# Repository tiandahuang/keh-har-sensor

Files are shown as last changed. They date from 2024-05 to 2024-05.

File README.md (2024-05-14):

# A Kinetic Energy Harvesting (KEH) sensor for Human Activity Recognition (HAR)
 
Design files for my thesis titled "Design of a Batteryless Sensor for Human Activity Recognition", submitted May 2024 towards an MS in Electrical and Computer Engineering at the University of Texas Austin and advised by Dr. Radu Marculescu.

## Abstract

Recent advancements in sensing technology coupled with the proliferation of
cheap, low power computing have enabled the growing popularity of wearable sensors
in everyday activities. Inertial sensing, particularly for human activity recognition
(HAR), has emerged as a ubiquitous tool across fitness, healthcare, and entertainment
applications. However, conventional wearable sensors rely on batteries, introducing
limitations in cost, environmental impact, and user burden.

This thesis explores a solution to the limitations of battery-powered operation
with the design and implementation of a wearable, kinetic energy harvesting (KEH)
powered wireless inertial sensor for batteryless HAR. The KEH-powered sensor is
energy optimized to require only 140µJ per set of accelerometer samples, translating
to an average power draw of 90µJ during continuous operation. The idle power
consumption is only 9.2µW while connected over Bluetooth. Energy harvesting is
achieved by a rotational unbalanced mass electromagnetic harvester with a peak
power output of 1.3mW.

## Device Summary

#### The full device assembly: The device is designed and assembled entirely from scratch. 

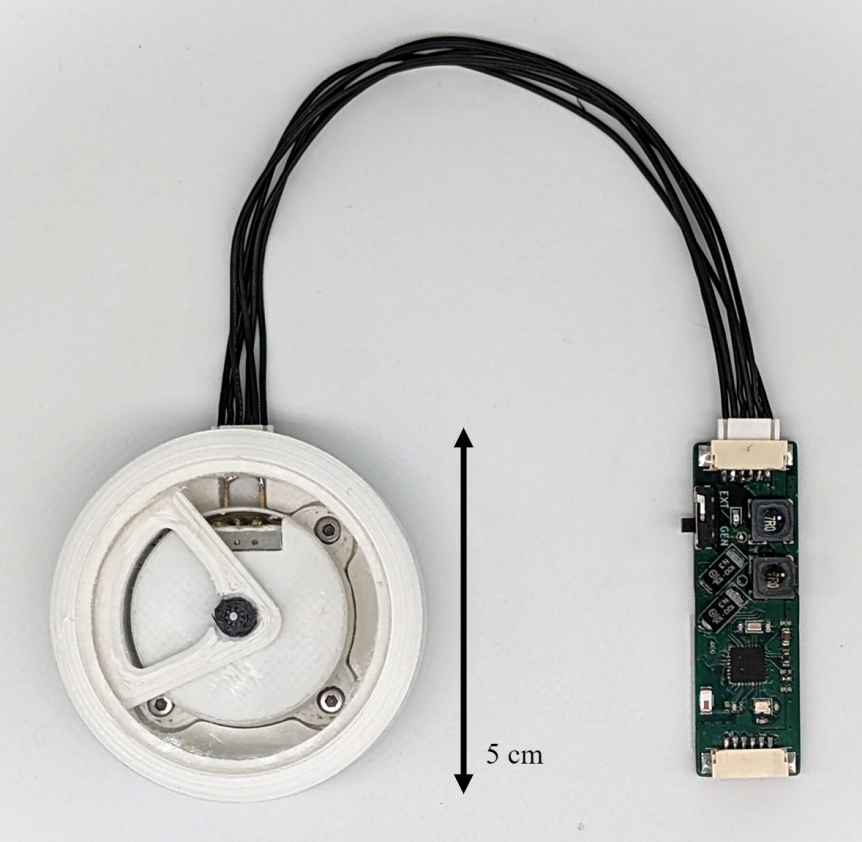
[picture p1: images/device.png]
full device


#### Component view of the entire device. Enclosures are located on the top row. There are four functional components, split between the Kinetic Energy Harvesting (KEH) Module (offset mass, rotor, stator), and the Power Conversion and Sensing/Communication Modules (PCB).

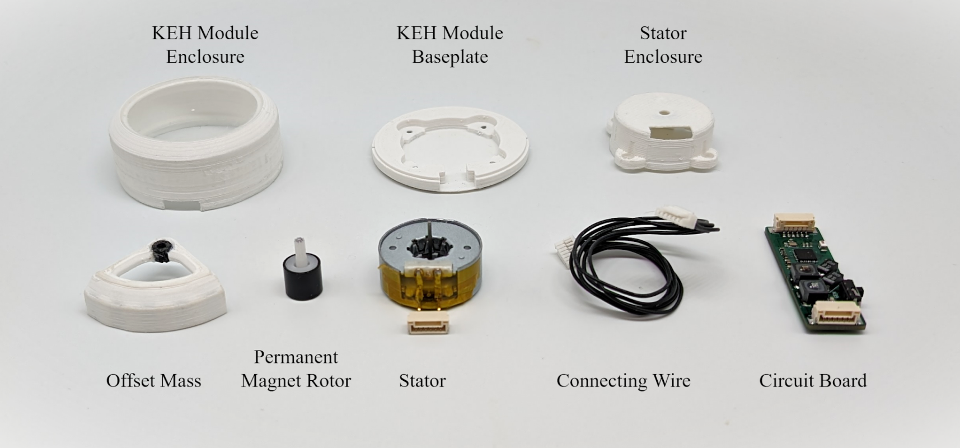
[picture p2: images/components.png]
device components


#### Full device block diagram. Energy harvested by the KEH Module (left) is converted to usable power by the Power Module (middle), which is used to sample an accelerometer and to transmit data by the Sensing Module (right). Energy storage capacitors buffer the usable power.

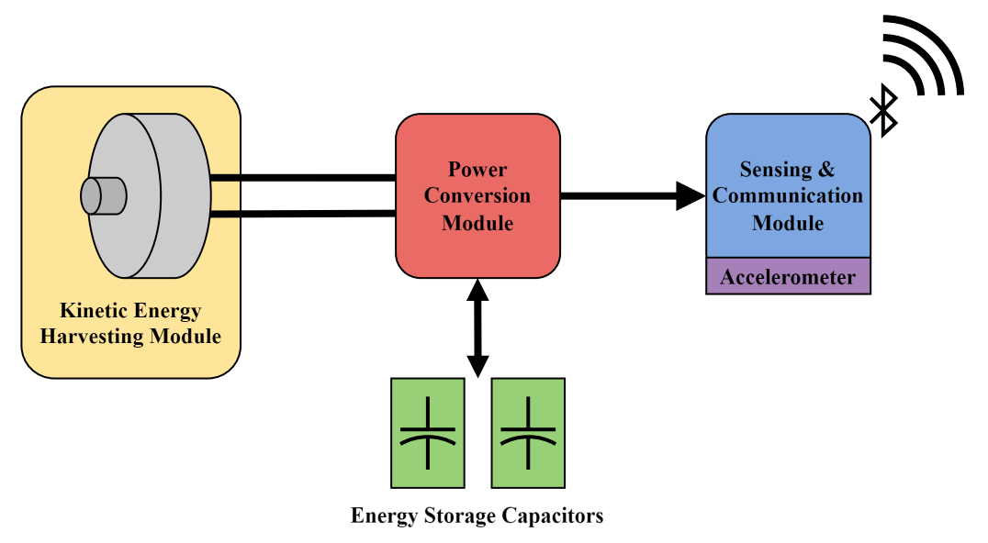
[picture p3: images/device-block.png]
device block diagram


## Physical Design

*Files are located in `./3d/*`*

The physical operation the device centers around the KEH Module, custom-designed to address the relatively high power requirements and tight space constraints of the wearable KEH sensor. The KEH Module is a rotational unbalanced mass EM harvester; this type of harvester is implemented using a statically-mounted stator and a rotor containing a permanent magnet and an attached offset mass. 

The KEH Module and its enclosure are primarily comprised of 3D-printed polylactic acid (PLA) thermoplastic. The top of the KEH Module is a 3mm acrylic panel, stiffening the assembly and providing stability to the top of the rotor. The stator and rotor are retrieved from a 28BYJ-48 geared unipolar stepper motor. For this application, the gears are removed and the stator is modified to be bipolar. The offset mass is also constructed from PLA, with steel M3 screws and fasteners for added weight. The mass totals 8.7g with a radius of 20mm.

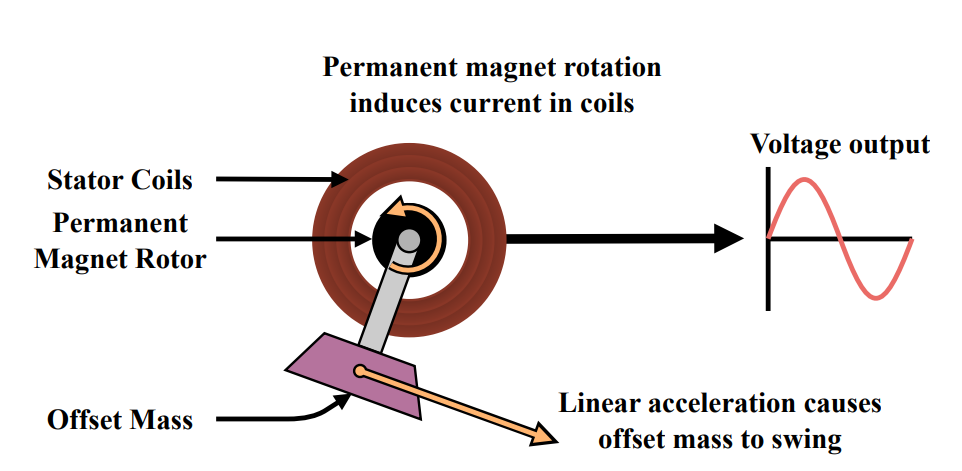
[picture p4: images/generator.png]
physical operation


## Firmware Design

*Files are located in `./firmware/*`*

The firmware architecture of device adheres to an event-driven paradigm, with a target of minimizing processor occupancy. By transferring execution context between various hardware-driven interrupt handlers, the total amount of processing time can be reduced. 

Initialization must be separated into a low-level initialization and BLE initialization
due to the significant power requirements of BLE: BLE initialization includes connecting to a listening device, which has an energy budget orders of magnitude higher than low-level initialization. 

After initialization is completed (including completing a BLE connection),
context is fully transferred to a series of hardware-driven interrupts. In steady-state
operation, all system execution is triggered by a periodic timer interrupt running every
100ms. The interrupt handler initiates ADC sampling; upon completion of the ADC
sample a subsequent hardware interrupt is triggered, executing energy-monitoring
logic. If energy is sufficient for the accelerometer to sample a set of data and for a
BLE packet to be sent, the accelerometer is woken up. Running independently of the
MCU, the accelerometer stores 16 samples of data within an internal first-in-first-out
buffer (FIFO). The filling of this FIFO then triggers a hardware interrupt in the
MCU, signaling the MCU to retrieve the FIFO data and to transmit the data over
BLE.

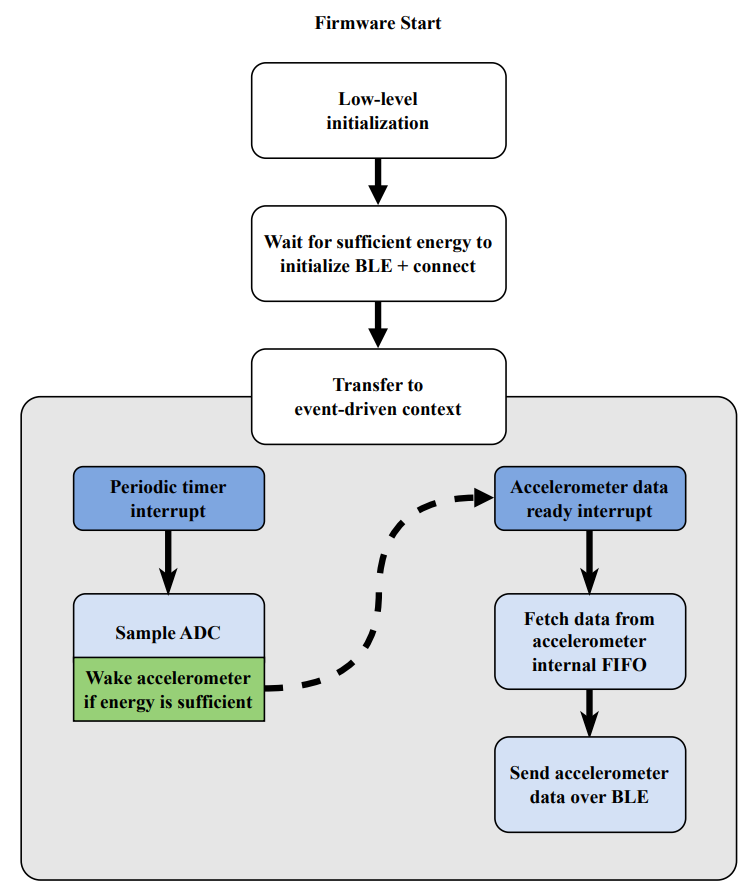
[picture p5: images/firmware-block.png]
firmware block diagram


## Electrical Design

*Files are located in `./pcb/*`*

A single PCB contains all electrical circuitry required for operation. This can be segmented into two modules, the Power Conversion Module and the Sensing/Communication Module. The Power Module contains the PMIC and energy storage; the Sensing Module contains the MCU and the accelerometer. 

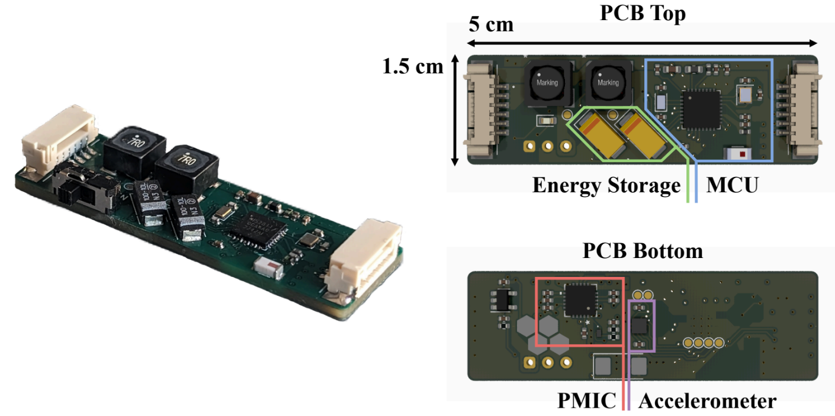
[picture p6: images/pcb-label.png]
pcb with labels


### Power Conversion Module

The Power Module performs a wide array of power regulation-related functions, needed to convert the KEH generator's low and variable peak-to-peak output voltage into a stable, usable VDD for the Sensing Module. The following functions are included:

1. **Amplification**: Coupled inductors and a transformer driver (similar in topology to an isolated synchronous boost converter) amplify the weak voltage output from the generator into a high peak-to-peak AC signal; this reduces diode voltage losses from rectification.
2. **Rectification**: A full-wave rectifier converts the input AC voltage into DC. This DC voltage must be high enough to step down to the final VDD.
3. **Step-Down Conversion & Regulation**: A switching regulator steps down the unstable DC output from the rectifier to the final VDD.
4. **Charge Management**: A bidirectional gate switches between charging storage capacitors (with excess energy) and discharging storage capacitors.

### Sensing/Communication Module

The Sensing Module contains an SPI-enabled triaxial accelerometer and a BLE MCU. Electrically, the implementation follows their respective datasheets.

### Major Components

| **Component** | **Part Number** | **Purpose** |
|:---:|:---:|:---:|
| PMIC | LTC3109 | Power rectification and management |
| BLE/MCU | nRF52811 | System control, data transmission |
| Accelerometer | BMA400 | Triaxial acceleration sampling, data buffering |

## Power Performance

### Power Generation

| **Measurement** | **Value** |
|:---:|:---:|
| Peak Voltage  | 350 mV  |
| Peak Current  | 4 mA |
| Peak Power | 1.3 mW  |

### Power Consumption

| **Event** | **Value** |
|:---:|:---:|
| Inrush | 23 µJ |
|  Hardware Initialization | 48 µJ |
| BLE Initialization | 620 µJ  |
| ADC Sample |  0.88 µJ  |
| Accelerometer & BLE Send | 102 µJ  |
| Leakage (Device Idle)  | 9.2 µW  |
|  Leakage (Open Circuit)  | 6 µW |

## File Structure

| **Folder** | **Description** | **Tool/Toolchain** |
|---|---|---|
| ./firmware | Device firmware and project files | SEGGER 5.42a |
| ./pcb | PCB schematic, layout, and project files | KiCAD 7.0 |
| ./3d | CAD files for generator and enclosures | SOLIDWORKS 2022 |

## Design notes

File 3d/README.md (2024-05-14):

*Please excuse the horrid naming.*

All parts are 3D printed using PLA, with the exception of `glass.SLDPRT`, which is laser-cut 1/8" acrylic. Mass is added to the PLA arm using embedded M3 bolts/nuts (total mass = 8.7g).

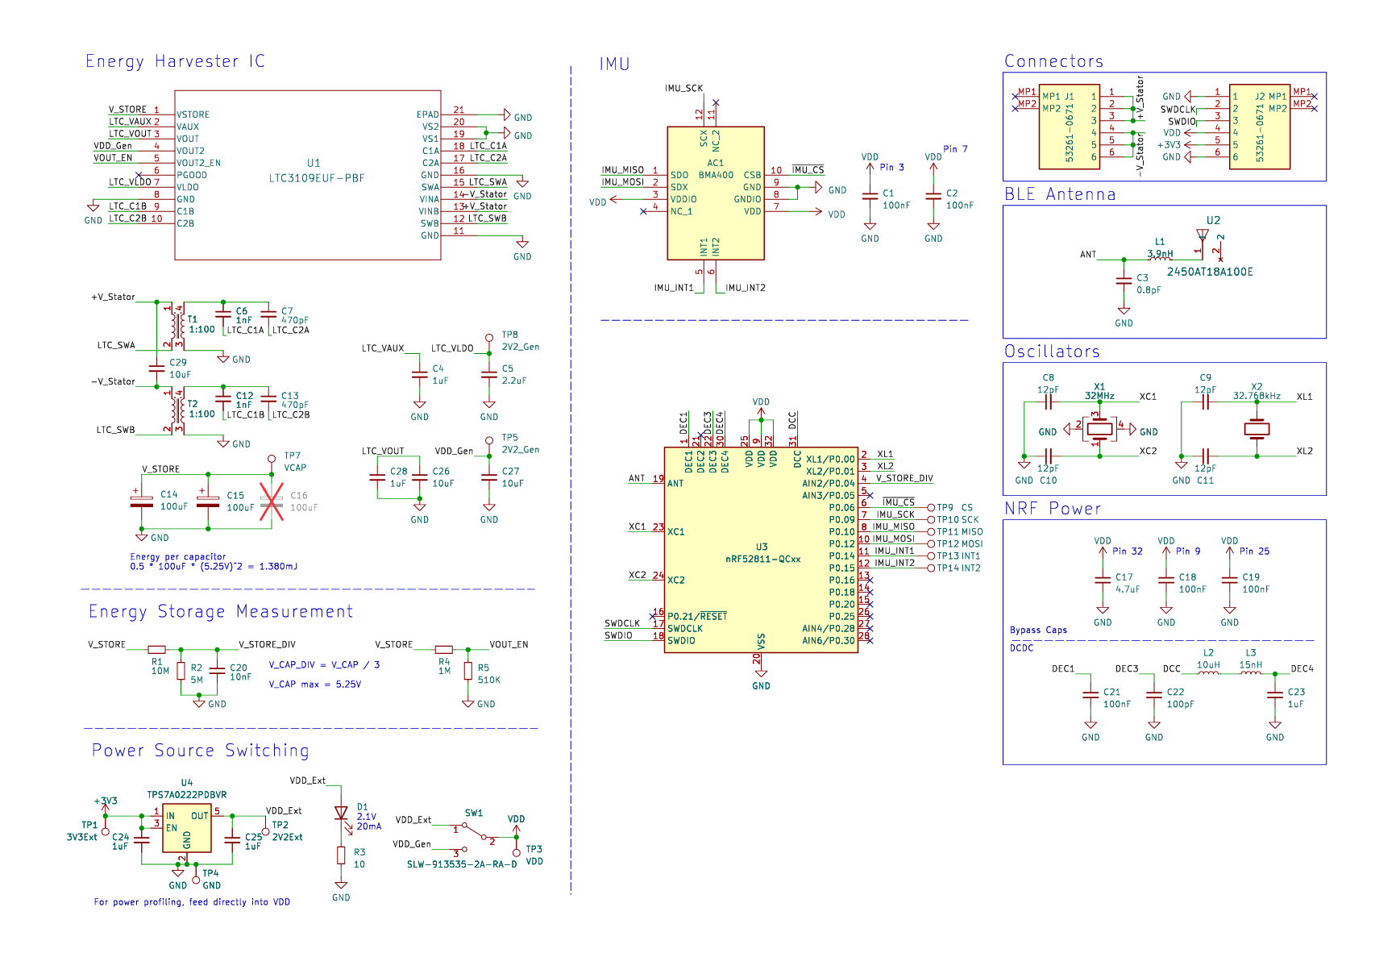
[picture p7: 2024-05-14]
pcb/images/schematic.png

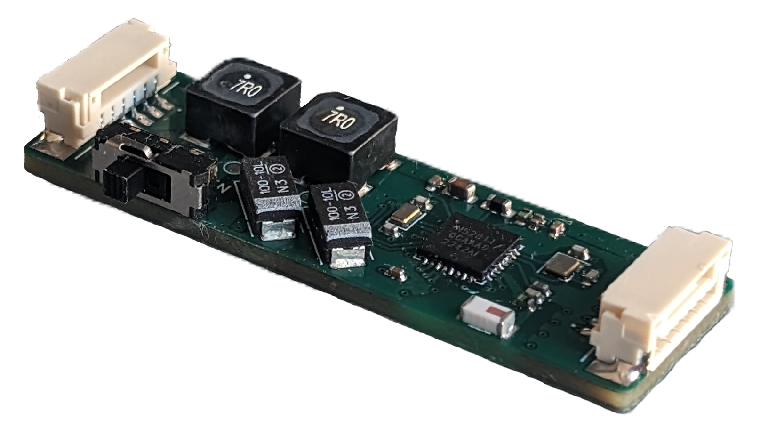
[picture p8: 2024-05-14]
pcb/images/pcb-actual.png

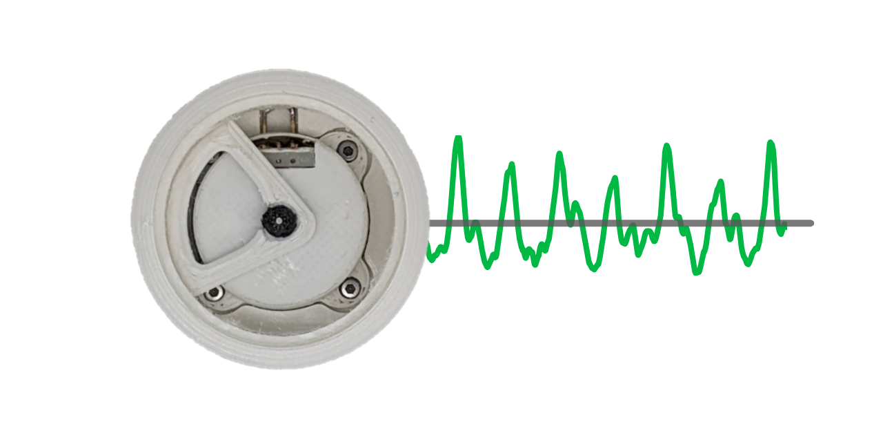
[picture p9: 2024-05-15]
images/preview.png

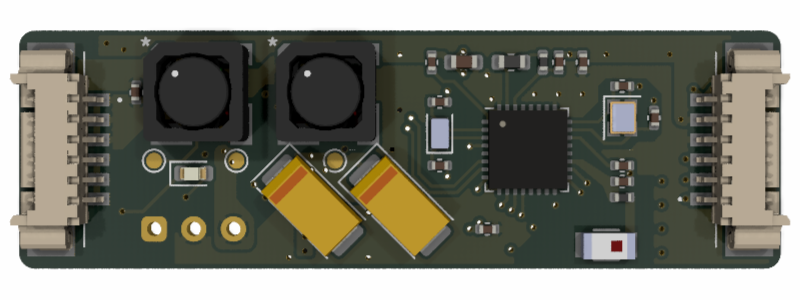
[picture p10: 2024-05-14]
pcb/images/imu-harvester-front.png

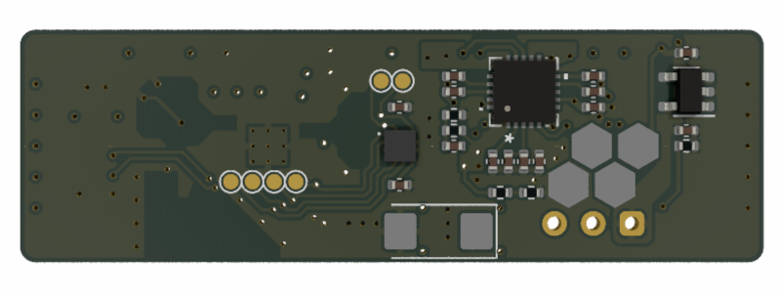
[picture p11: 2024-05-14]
pcb/images/imu-harvester-back.png

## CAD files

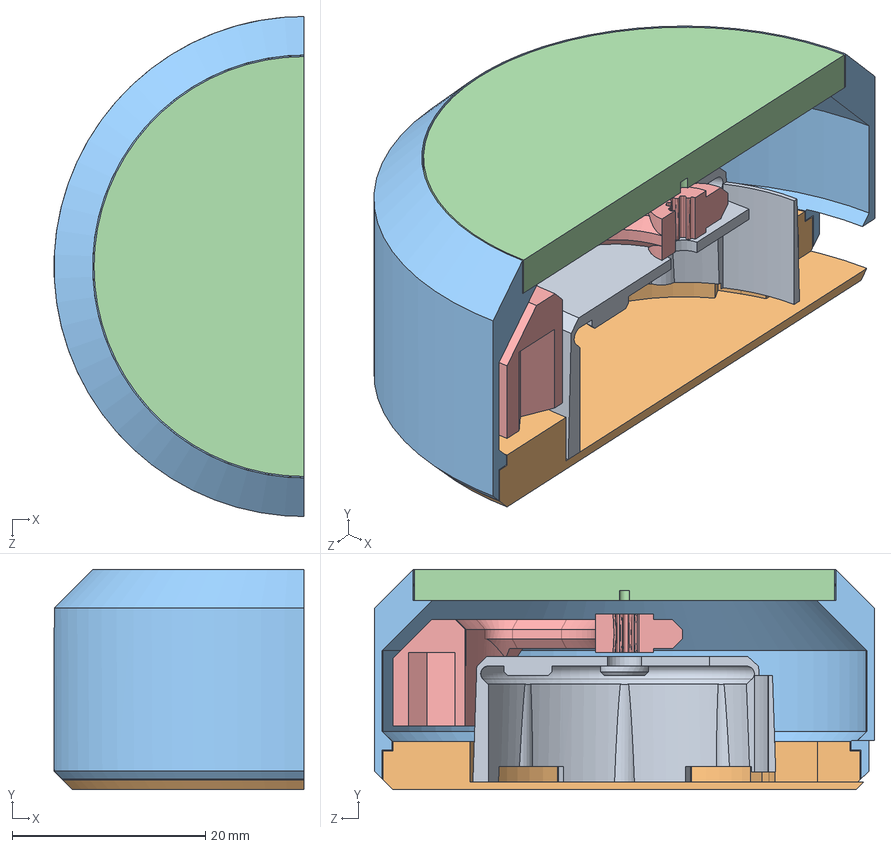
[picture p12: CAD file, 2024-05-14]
3d/0.SLDASM
25.9 x 22.8 x 51.8 mm
base
base2
base3
glass
arm

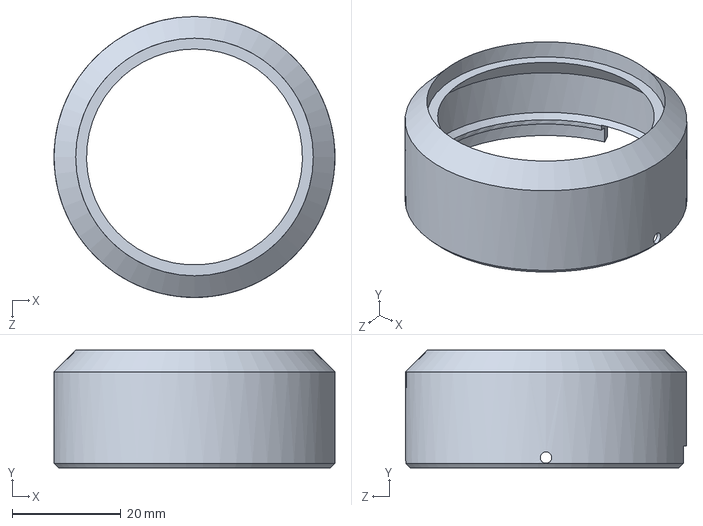
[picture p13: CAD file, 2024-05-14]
3d/base3.SLDPRT
51.8 x 21.7 x 51.8 mm

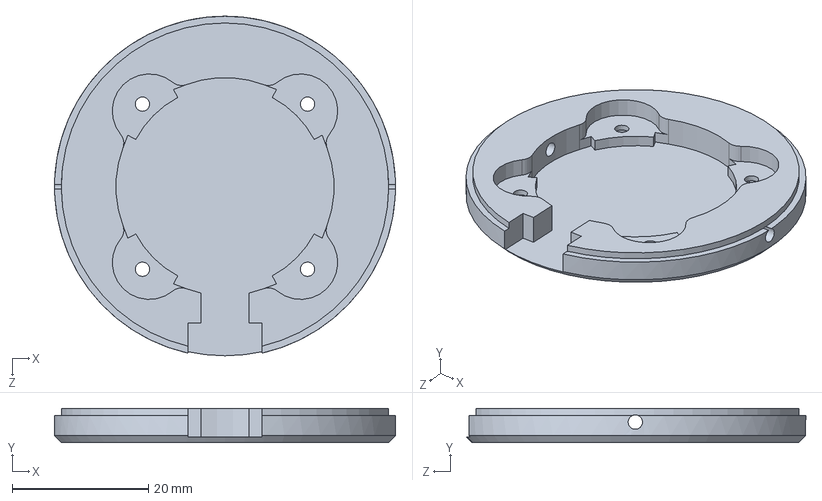
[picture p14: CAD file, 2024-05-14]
3d/base2.SLDPRT
50.0 x 5.00 x 49.8 mm

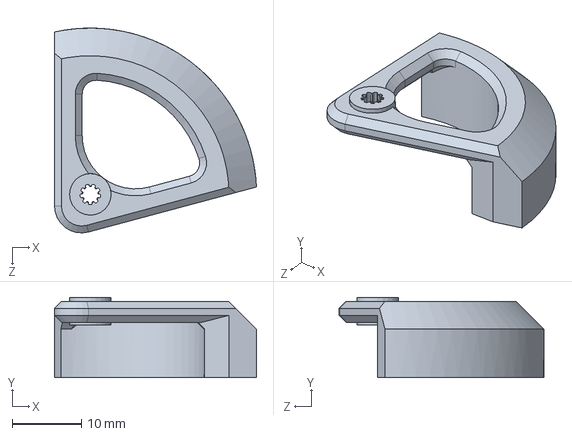
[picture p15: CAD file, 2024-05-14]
3d/arm.SLDPRT
29.2 x 11.6 x 29.6 mm

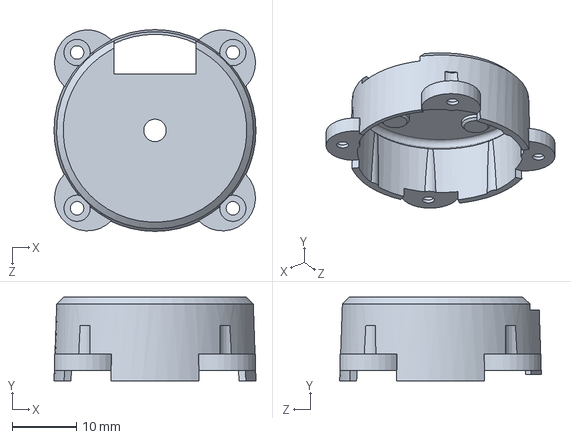
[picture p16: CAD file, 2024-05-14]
3d/base.SLDPRT
31.4 x 13.0 x 31.4 mm

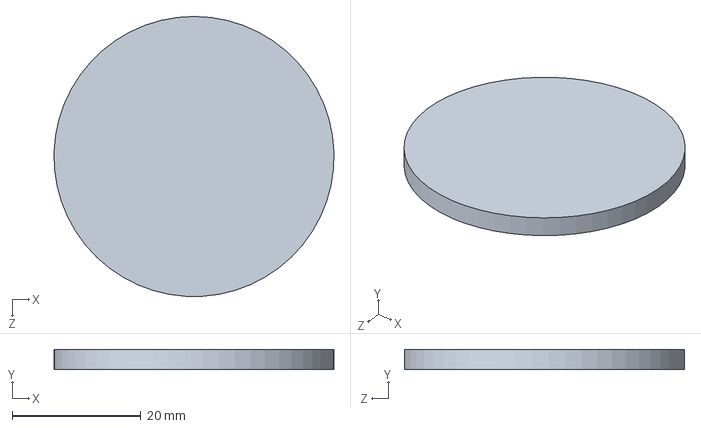
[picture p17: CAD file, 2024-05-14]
3d/glass.SLDPRT
43.5 x 3.17 x 43.5 mm

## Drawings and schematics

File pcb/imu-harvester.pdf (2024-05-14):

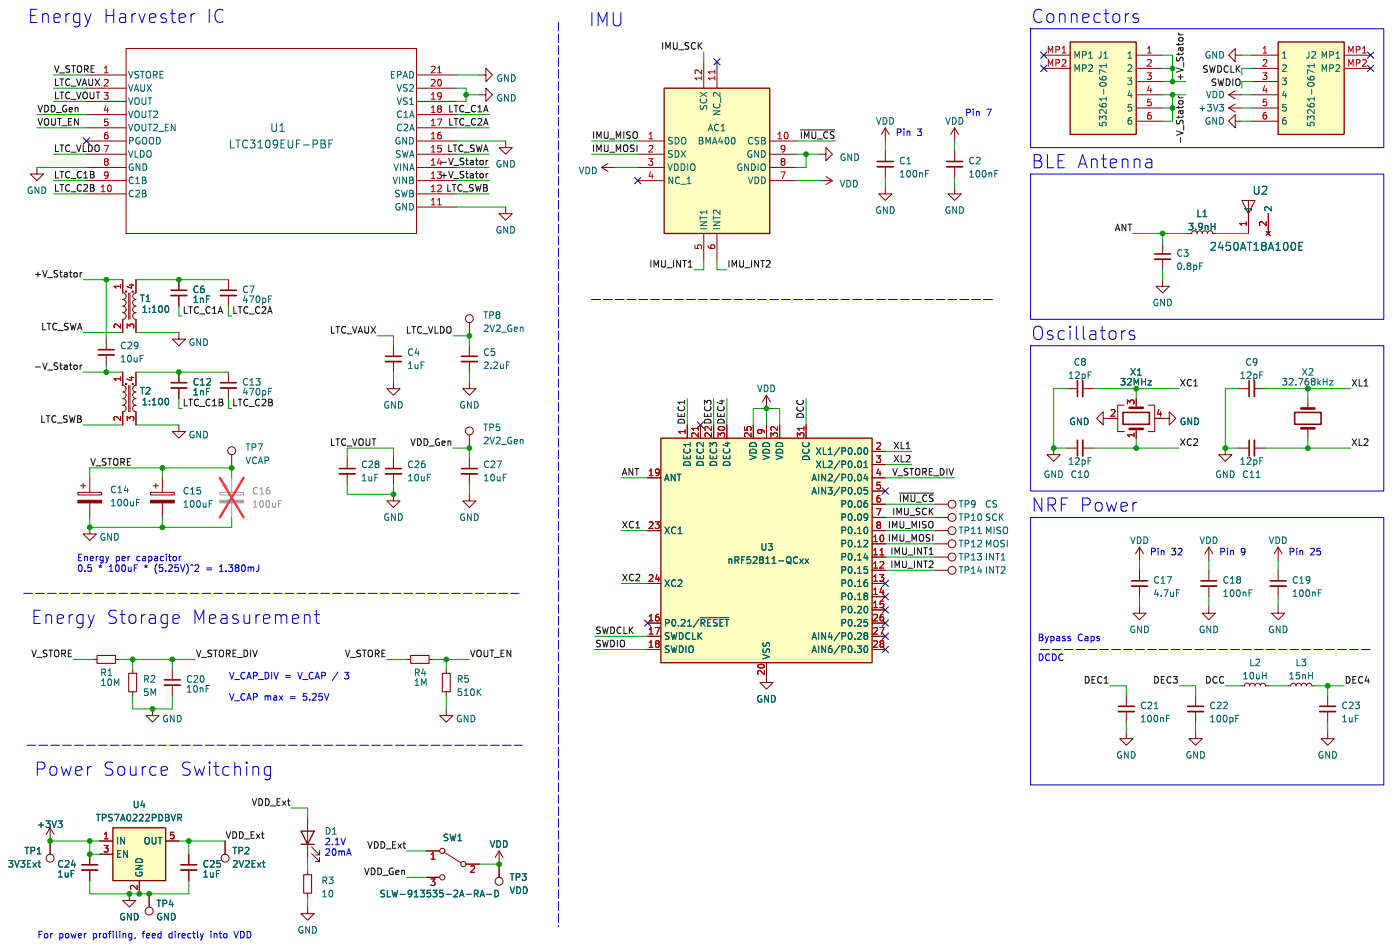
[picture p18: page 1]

1 P0.12 10 P0.14 11 P0.15 12 P0.16 13 P0.18 14 P0.20 15 P0.21/~{RESET} 16 SWDCLK 17 SWDIO 18 ANT 19 XL1/P0.00 2 VSS 20 DEC2 21 DEC3 22 XC1 23 XC2 24 VDD 25 P0.25 26 AIN4/P0.28 27 AIN6/P0.30 28 XL2/P0.01 3 DEC4 30 DCC 31 VDD 32 AIN2/P0.04 4 AIN3/P0.05 5 P0.06 6 P0.09 7 P0.10 8 VDD
nRF52811-QCxx GND

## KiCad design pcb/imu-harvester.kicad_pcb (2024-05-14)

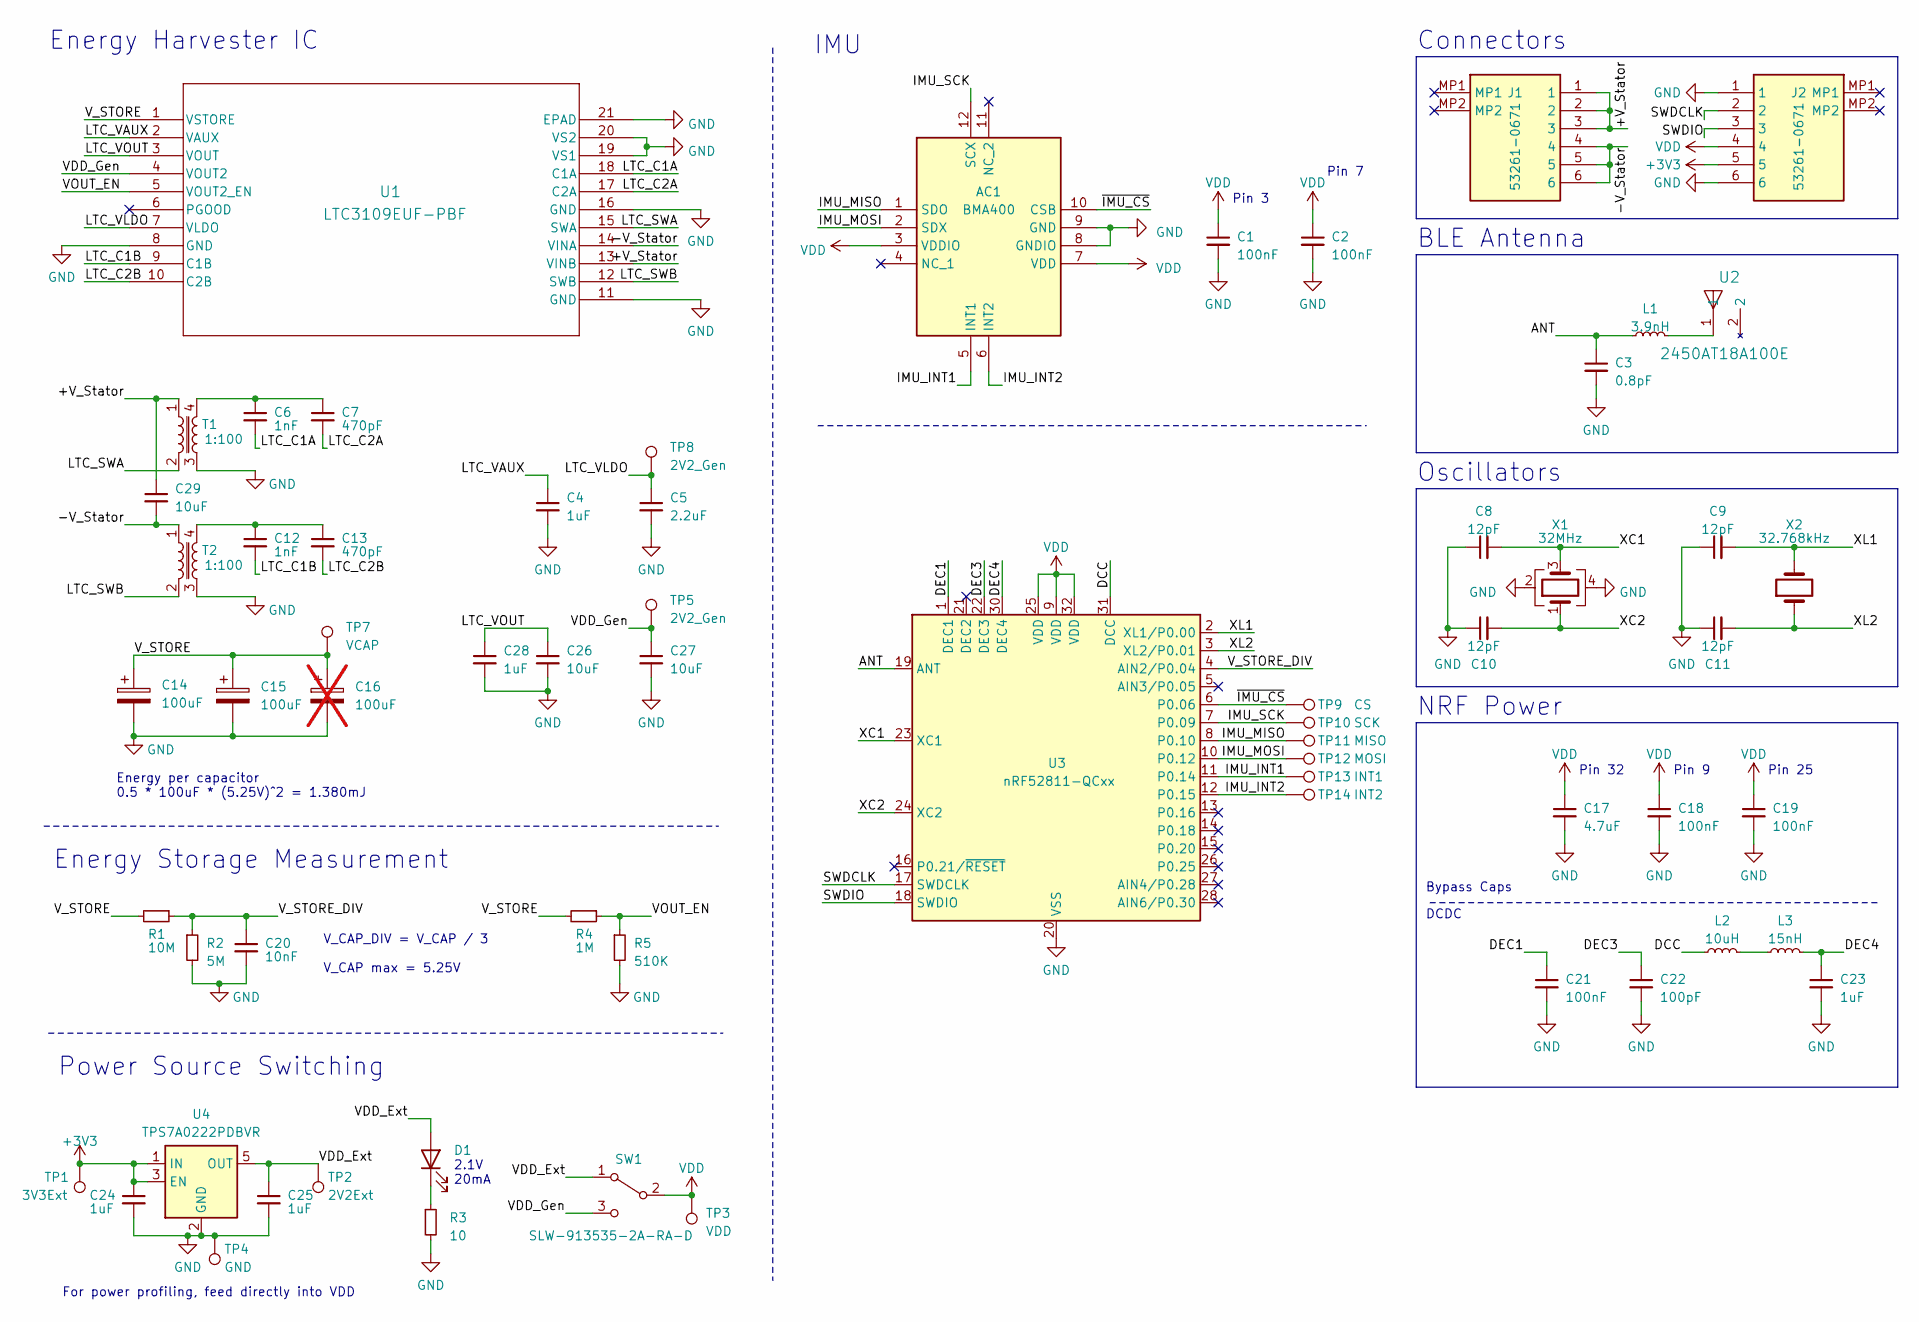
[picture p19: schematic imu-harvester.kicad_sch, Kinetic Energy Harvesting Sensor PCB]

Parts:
AC1: BMA400; BOSCH_LGA-12; Mouser Part Number 262-BMA400
C1, C2, C18, C19, C21: 100nF; C_0402_1005Metric; Manufacturer_Part_Number KGM05AR71C104KN
C3: 0.8pF; C_0402_1005Metric; Manufacturer_Part_Number GRM1555C1ER80BA01D
C4, C23, C24, C25, C28: 1uF; C_0402_1005Metric; Manufacturer_Part_Number CM05X7R105K06AH-HE
C5: 2.2uF; C_0402_1005Metric; Manufacturer_Part_Number GRM155Z71A225KE01D
C6, C12: 1nF; C_0402_1005Metric; Manufacturer_Part_Number C0402C102KCRACAUTO
C7, C13: 470pF; C_0402_1005Metric; Manufacturer_Part_Number KGM05ACG1H471JH
C8, C9, C10, C11: 12pF; C_0402_1005Metric; Manufacturer_Part_Number KGM05ACG1H120JN
C14: 100uF; CP_EIA-6032-28_Kemet-C; Manufacturer_Part_Number TL3C107K010C0200
C15: 100uF; CP_EIA-6032-28_Kemet-C
C16: 100uF; CP_EIA-6032-28_Kemet-C; not fitted
C17: 4.7uF; C_0603_1608Metric; Manufacturer_Part_Number GRM188Z71C475KE21D
C20: 10nF; C_0402_1005Metric; Manufacturer_Part_Number C0402C103K1RACAUTO
C22: 100pF; C_0402_1005Metric; Manufacturer_Part_Number KGM05ACG1H101JN
C26, C29: 10uF; C_0402_1005Metric; Manufacturer_Part_Number CM05X7R105K06AH-HE
C27: 10uF; C_0402_1005Metric; Manufacturer_Part_Number GRM155Z71A225KE01D
D1: LO Q976.01-P2R2-25-1; LED_0603_1608Metric; Manufacturer_Part_Number LO Q976.01-P2R2-25-1
J1, J2: 53261-0671; 532610671; Mouser Part Number 538-53261-0671
L1: 3.9nH; L_0402_1005Metric; Manufacturer_Part_Number LQG15WZ3N9B02D
L2: 10uH; L_0603_1608Metric; Manufacturer_Part_Number KLZ1608MHR100WTD25
L3: 15nH; L_0402_1005Metric; Manufacturer_Part_Number LQG15WZ15NG02D
R1: 10M; R_0402_1005Metric; Manufacturer_Part_Number RCC040210M0FKED
R2: 5M; R_0402_1005Metric; Manufacturer_Part_Number CRCW04024M99FKED
R3: 10; R_0402_1005Metric; Manufacturer_Part_Number RCC040210R0FKED
R4: 1M; R_0402_1005Metric; Manufacturer_Part_Number RCC040210M0FKED
R5: 510K; R_0402_1005Metric; Manufacturer_Part_Number CRCW04024M99FKED
SW1: SLW-913535-2A-RA-D; Manufacturer_Part_Number SLW-913535-2A-RA-D
T1, T2: 1:100; 74488540070; Manufacturer_Part_Number 74488540070
TP1: 3V3Ext; Testpoint_Hex_D3.0
TP2: 2V2Ext; Testpoint_Hex_D3.0
TP3: VDD; Testpoint_Hex_D3.0
TP4: GND; Testpoint_Hex_D3.0
TP5, TP8: 2V2_Gen; TestPoint_Pad_D1.0mm
TP7: VCAP; TestPoint_Pad_D1.0mm
TP9: CS; TestPoint_Pad_D1.0mm
TP10: SCK; TestPoint_Pad_D1.0mm
TP11: MISO; TestPoint_Pad_D1.0mm
TP12: MOSI; TestPoint_Pad_D1.0mm
TP13: INT1; TestPoint_Pad_D1.0mm
TP14: INT2; TestPoint_Pad_D1.0mm
U1: LTC3109EUF-PBF; QFN-20_UF_LIT; Manufacturer_Part_Number LTC3109EUF#PBF
U2: 2450AT18A100E; 2450AT18A100E_JOT; Manufacturer_Part_Number 2450AT18A100E
U3: nRF52811-QCxx; QFN-32-1EP_5x5mm_P0.5mm_EP3.6x3.6mm_ThermalVias; Manufacturer_Part_Number nRF52811-QCAA-R
U4: TPS7A0222PDBVR; SOT-23-5; Manufacturer_Part_Number TPS7A0222PDBVR
X1: 32MHz; Crystal_SMD_2016-4Pin_2.0x1.6mm; Manufacturer_Part_Number ECS-320-8-37B2-JTY-TR
X2: 32.768kHz; Crystal_SMD_2012-2Pin_2.0x1.2mm; Manufacturer_Part_Number ECS-.327-9-12R-TR

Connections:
+3V3: C24.1, J2.5, TP1.1, U4.1 (IN), U4.3 (EN)
/+V_Stator: C29.1, J1.1, J1.2, J1.3, T1.1, U1.13 (VINB)
/-V_Stator: C29.2, J1.4, J1.5, J1.6, T2.1, U1.14 (VINA)
/ANT: C3.1, L1.1, U3.19 (ANT)
/DCC: L2.1, U3.31 (DCC)
/DEC1: C21.1, U3.1 (DEC1)
/DEC3: C22.1, U3.22 (DEC3)
/DEC4: C23.1, L3.2, U3.30 (DEC4)
/IMU_INT1: AC1.5 (INT1), TP13.1, U3.11 (P0.14)
/IMU_INT2: AC1.6 (INT2), TP14.1, U3.12 (P0.15)
/IMU_MISO: AC1.1 (SDO), TP11.1, U3.8 (P0.10)
/IMU_MOSI: AC1.2 (SDX), TP12.1, U3.10 (P0.12)
/IMU_SCK: AC1.12 (SCX), TP10.1, U3.7 (P0.09)
/LTC_C1A: C6.2, U1.18 (C1A)
/LTC_C1B: C12.2, U1.9 (C1B)
/LTC_C2A: C7.2, U1.17 (C2A)
/LTC_C2B: C13.2, U1.10 (C2B)
/LTC_SWA: T1.2, U1.15 (SWA)
/LTC_SWB: T2.2, U1.12 (SWB)
/LTC_VAUX: C4.1, U1.2 (VAUX)
/LTC_VLDO: C5.1, TP8.1, U1.7 (VLDO)
/LTC_VOUT: C26.1, C28.1, U1.3 (VOUT)
/SWDCLK: J2.2, U3.17 (SWDCLK)
/SWDIO: J2.3, U3.18 (SWDIO)
/VDD_Ext: C25.1, D1.2 (A), SW1.1 (A), TP2.1, U4.5 (OUT)
/VDD_Gen: C27.1, SW1.3 (C), TP5.1, U1.4 (VOUT2)
/VOUT_EN: R4.1, R5.1, U1.5 (VOUT2_EN)
/V_STORE: C14.1, C15.1, C16.1, R1.2, R4.2, TP7.1, U1.1 (VSTORE)
/V_STORE_DIV: C20.1, R1.1, R2.1, U3.4 (AIN2/P0.04)
/XC1: C8.2, U3.23 (XC1), X1.3
/XC2: C10.2, U3.24 (XC2), X1.1
/XL1: C9.2, U3.2 (XL1/P0.00), X2.2
/XL2: C11.2, U3.3 (XL2/P0.01), X2.1
/~IMU_CS: AC1.10 (CSB), TP9.1, U3.6 (P0.06)
GND: AC1.8 (GNDIO), AC1.9 (GND), C1.2, C2.2, C3.2, C4.2, C5.2, C8.1, C9.1, C10.1, C11.1, C14.2, C15.2, C16.2, C17.2, C18.2, C19.2, C20.2, C21.2, C22.2, C23.2, C24.2, C25.2, C26.2, C27.2, C28.2, J2.1, J2.6, R2.2, R3.2, R5.2, T1.3, T2.3, TP4.1, U1.8 (GND), U1.11 (GND), U1.16 (GND), U1.19 (VS1), U1.20 (VS2), U1.21 (EPAD), U3.20 (VSS), U3.29 (VSS), U3.33 (VSS), U4.2 (GND), X1.2, X1.4
unnamed: C6.1, C7.1, T1.4
unnamed: C12.1, C13.1, T2.4
unnamed: D1.1 (K), R3.1
unnamed: L1.2, U2.1
unnamed: L2.2, L3.1
VDD: AC1.3 (VDDIO), AC1.7 (VDD), C1.1, C2.1, C17.1, C18.1, C19.1, J2.4, SW1.2 (B), TP3.1, U3.9 (VDD), U3.25 (VDD), U3.32 (VDD)

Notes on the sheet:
V_CAP_DIV = V_CAP / 3 V_CAP max = 5.25V
Energy Storage Measurement
Pin 3
Power Source Switching
Pin 9
NRF Power
Connectors
DCDC
IMU
2.1V 20mA
Bypass Caps
BLE Antenna
Oscillators
Energy per capacitor 0.5 * 100uF * (5.25V)^2 = 1.380mJ
Pin 32
For power profiling, feed directly into VDD
Pin 25
Energy Harvester IC
Pin 7

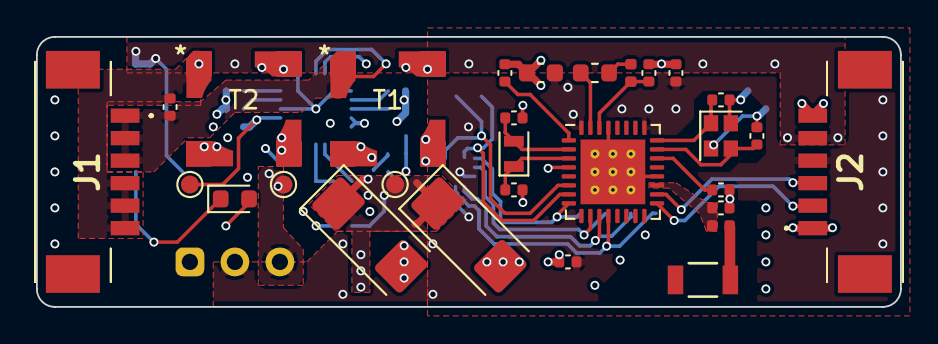
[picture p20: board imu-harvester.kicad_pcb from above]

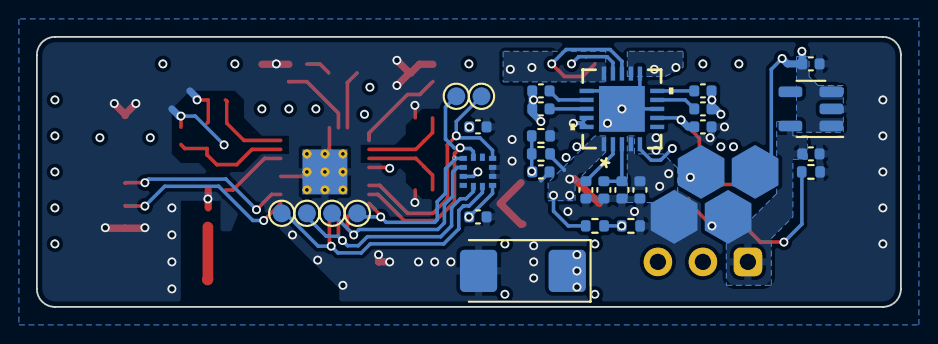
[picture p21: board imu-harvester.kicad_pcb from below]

Board: 4 copper layers, 48.0 x 15.0 mm, 63 parts (33 on the bottom side), 41 nets.

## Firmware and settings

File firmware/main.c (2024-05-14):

/**
 * Copyright (c) 2014 - 2021, Nordic Semiconductor ASA
 *
 * All rights reserved.
 *
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
 * 3. Neither the name of Nordic Semiconductor ASA nor the names of its
 *    contributors may be used to endorse or promote products derived from this
 *    software without specific prior written permission.
 *
 * 4. This software, with or without modification, must only be used with a
 *    Nordic Semiconductor ASA integrated circuit.
 *
 * 5. Any software provided in binary form under this license must not be reverse
 *    engineered, decompiled, modified and/or disassembled.
 *
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
 */

#include "app_common.h"
#include "app_debug.h"
#include "nrf.h"
#include "nrf_pwr_mgmt.h"
#include "nrfx_gpiote.h"
#include "nrfx_clock.h"
#include "nrf_sdh.h"

#include "app_timer.h"
#include "app_scheduler.h"

#include "app_ble_nus.h"
#include "app_accelerometer.h"
#include "app_voltage.h"

#define APP_SCHED_EVENT_SIZE    APP_TIMER_SCHED_EVENT_DATA_SIZE
#define APP_SCHED_QUEUE_SIZE    10

/**@brief Function for assert macro callback.
 *
 * @details This function will be called in case of an assert in the SoftDevice.
 *
 * @warning This handler is an example only and does not fit a final product. You need to analyse
 *          how your product is supposed to react in case of Assert.
 * @warning On assert from the SoftDevice, the system can only recover on reset.
 *
 * @param[in] line_num    Line number of the failing ASSERT call.
 * @param[in] p_file_name File name of the failing ASSERT call.
 */
void assert_nrf_callback(uint16_t line_num, const uint8_t *p_file_name) {
    app_error_handler(42, line_num, p_file_name);
}

/**@brief Function for handling the idle state (main loop).
 *
 * @details If there is no pending log operation, then sleep until next the next event occurs.
 */
static void idle_state_handle(void) {
    if (debug_process() == false) {
        nrf_pwr_mgmt_run();
    }
}

#if POWER_PROFILING_ENABLED
static void start_sampling_accel(void *p_event_data, uint16_t event_size) {
    debug_log("(debug timer) v store %d", voltage_read_v_store());
    debug_log("(debug timer) accelerometer set to wake");
    accelerometer_wake(true, true);
}

APP_TIMER_DEF(accel_sample_timer_id);
void accel_sample_handler(void *p_context) {
    app_sched_event_put(NULL, 0, start_sampling_accel);
}

void power_profiling_init(void) {
    debug_log("power profiling enabled. starting timer with period "STRINGIFY(POWER_PROFILING_PERIOD_MS)" ms");
    
    ret_code_t err_code;
    err_code = app_timer_create(&accel_sample_timer_id,
                                APP_TIMER_MODE_REPEATED,
                                accel_sample_handler);
    err_code = app_timer_start(accel_sample_timer_id,
                               APP_TIMER_TICKS(POWER_PROFILING_PERIOD_MS),
                               NULL);
}
#endif

/**@brief Application main function.
 */
int main(void) {

    // Initialize.
    nrf_pwr_mgmt_init();
    debug_init();
    nrfx_gpiote_init();
    APP_SCHED_INIT(APP_SCHED_EVENT_SIZE, APP_SCHED_QUEUE_SIZE);
    nrf_sdh_enable_request();

    app_timer_init();
    accelerometer_init();
    voltage_init();

    #if POWER_PROFILING_ENABLED

    power_profiling_init();

    #else 

    debug_log("finished HW init. waiting for enough energy to init BLE."); debug_force_flush();
    voltage_wait_for_v_store_thresh(V_STORE_LVL_BLE_INIT);

    #endif
    
    debug_log("initializing BLE");

    // Start BLE
    ble_all_services_init();
    advertising_start(false);

    app_timer_init();
    voltage_init();

    // Start execution.
    debug_log("initialization finished");

    // Enter main loop.
    while (true) {
        app_sched_execute();
        idle_state_handle();
    }
}

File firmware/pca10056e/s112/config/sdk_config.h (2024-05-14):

/**
 * Copyright (c) 2017 - 2021, Nordic Semiconductor ASA
 *
 * All rights reserved.
 *
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
 * 3. Neither the name of Nordic Semiconductor ASA nor the names of its
 *    contributors may be used to endorse or promote products derived from this
 *    software without specific prior written permission.
 *
 * 4. This software, with or without modification, must only be used with a
 *    Nordic Semiconductor ASA integrated circuit.
 *
 * 5. Any software provided in binary form under this license must not be reverse
 *    engineered, decompiled, modified and/or disassembled.
 *
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
 */



#ifndef SDK_CONFIG_H
#define SDK_CONFIG_H
// <<< Use Configuration Wizard in Context Menu >>>\n
#ifdef USE_APP_CONFIG
#include "app_config.h"
#endif
// <h> Board Support 

//==========================================================
// <q> BSP_BTN_BLE_ENABLED  - bsp_btn_ble - Button Control for BLE
 

#ifndef BSP_BTN_BLE_ENABLED
#define BSP_BTN_BLE_ENABLED 0
#endif

// </h> 
//==========================================================

// <h> nRF_BLE 

//==========================================================
// <q> BLE_ADVERTISING_ENABLED  - ble_advertising - Advertising module
 

#ifndef BLE_ADVERTISING_ENABLED
#define BLE_ADVERTISING_ENABLED 1
#endif

// <e> BLE_DTM_ENABLED - ble_dtm - Module for testing RF/PHY using DTM commands
//==========================================================
#ifndef BLE_DTM_ENABLED
#define BLE_DTM_ENABLED 0
#endif
// <o> NRF_RADIO_ANTENNA_PIN_1 - Antenna 1 GPIO pin 
#ifndef NRF_RADIO_ANTENNA_PIN_1
#define NRF_RADIO_ANTENNA_PIN_1 21
#endif

// <o> NRF_RADIO_ANTENNA_PIN_2 - Antenna 2 GPIO pin 
#ifndef NRF_RADIO_ANTENNA_PIN_2
#define NRF_RADIO_ANTENNA_PIN_2 23
#endif

// <o> NRF_RADIO_ANTENNA_PIN_3 - Antenna 3 GPIO pin 
#ifndef NRF_RADIO_ANTENNA_PIN_3
#define NRF_RADIO_ANTENNA_PIN_3 26
#endif

// <o> NRF_RADIO_ANTENNA_PIN_4 - Antenna 4 GPIO pin 
#ifndef NRF_RADIO_ANTENNA_PIN_4
#define NRF_RADIO_ANTENNA_PIN_4 27
#endif

// <o> NRF_RADIO_ANTENNA_PIN_5 - Antenna 5 GPIO pin 
#ifndef NRF_RADIO_ANTENNA_PIN_5
#define NRF_RADIO_ANTENNA_PIN_5 28
#endif

// <o> NRF_RADIO_ANTENNA_PIN_6 - Antenna 6 GPIO pin 
#ifndef NRF_RADIO_ANTENNA_PIN_6
#define NRF_RADIO_ANTENNA_PIN_6 29
#endif

// <o> NRF_RADIO_ANTENNA_PIN_7 - Antenna 7 GPIO pin 
#ifndef NRF_RADIO_ANTENNA_PIN_7
#define NRF_RADIO_ANTENNA_PIN_7 30
#endif

// <o> NRF_RADIO_ANTENNA_PIN_8 - Antenna 8 GPIO pin 
#ifndef NRF_RADIO_ANTENNA_PIN_8
#define NRF_RADIO_ANTENNA_PIN_8 31
#endif

// <o> NRF_RADIO_ANTENNA_COUNT  
#ifndef NRF_RADIO_ANTENNA_COUNT
#define NRF_RADIO_ANTENNA_COUNT 12
#endif

// <o> DTM_RADIO_IRQ_PRIORITY - RADIO interrupt priority 
#ifndef DTM_RADIO_IRQ_PRIORITY
#define DTM_RADIO_IRQ_PRIORITY 2
#endif

// <o> DTM_TIMER_IRQ_PRIORITY - DTM timer interrupt priority 
#ifndef DTM_TIMER_IRQ_PRIORITY
#define DTM_TIMER_IRQ_PRIORITY 3
#endif

// <o> DTM_ANOMALY_172_TIMER_IRQ_PRIORITY - DTM anomaly 172 timer interrupt priority 
#ifndef DTM_ANOMALY_172_TIMER_IRQ_PRIORITY
#define DTM_ANOMALY_172_TIMER_IRQ_PRIORITY 2
#endif

// <o> NRF_DTM_TIMER_INSTANCE  - DTM TIMER instance
 
// <0=> TIMER0 
// <2=> TIMER2 

#ifndef NRF_DTM_TIMER_INSTANCE
#define NRF_DTM_TIMER_INSTANCE 0
#endif

// </e>

// <q> BLE_RACP_ENABLED  - ble_racp - Record Access Control Point library
 

#ifndef BLE_RACP_ENABLED
#define BLE_RACP_ENABLED 0
#endif

// <e> NRF_BLE_CONN_PARAMS_ENABLED - ble_conn_params - Initiating and executing a connection parameters negotiation procedure
//==========================================================
#ifndef NRF_BLE_CONN_PARAMS_ENABLED
#define NRF_BLE_CONN_PARAMS_ENABLED 1
#endif
// <o> NRF_BLE_CONN_PARAMS_MAX_SLAVE_LATENCY_DEVIATION - The largest acceptable deviation in slave latency. 
// <i> The largest deviation (+ or -) from the requested slave latency that will not be renegotiated.

#ifndef NRF_BLE_CONN_PARAMS_MAX_SLAVE_LATENCY_DEVIATION
#define NRF_BLE_CONN_PARAMS_MAX_SLAVE_LATENCY_DEVIATION 499
#endif

// <o> NRF_BLE_CONN_PARAMS_MAX_SUPERVISION_TIMEOUT_DEVIATION - The largest acceptable deviation (in 10 ms units) in supervision timeout. 
// <i> The largest deviation (+ or -, in 10 ms units) from the requested supervision timeout that will not be renegotiated.

#ifndef NRF_BLE_CONN_PARAMS_MAX_SUPERVISION_TIMEOUT_DEVIATION
#define NRF_BLE_CONN_PARAMS_MAX_SUPERVISION_TIMEOUT_DEVIATION 65535
#endif

// </e>

// <e> NRF_BLE_GATT_ENABLED - nrf_ble_gatt - GATT module
//==========================================================
#ifndef NRF_BLE_GATT_ENABLED
#define NRF_BLE_GATT_ENABLED 1
#endif
// <q> NRF_BLE_GATT_MTU_EXCHANGE_INITIATION_ENABLED  - Enable GATT MTU exchange initiation
 

#ifndef NRF_BLE_GATT_MTU_EXCHANGE_INITIATION_ENABLED
#define NRF_BLE_GATT_MTU_EXCHANGE_INITIATION_ENABLED 1
#endif

// </e>
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
